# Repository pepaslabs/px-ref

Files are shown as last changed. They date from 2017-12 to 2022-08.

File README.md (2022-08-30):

# PX Ref

This is an LTZ1000-based 7V reference.

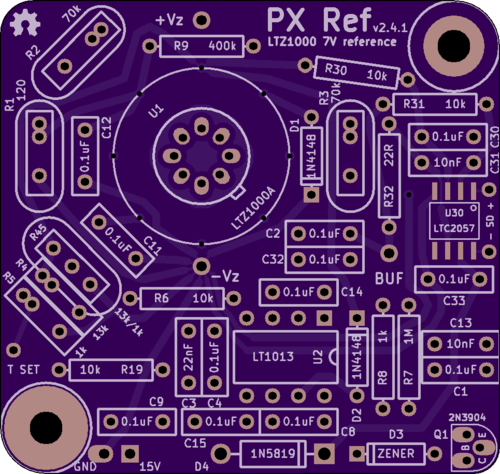
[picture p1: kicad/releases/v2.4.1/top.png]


Specifically, this is my board layout of a circuit [published](http://www.eevblog.com/forum/metrology/ultra-precision-reference-ltz1000/msg249123/#msg249123) by Andreas (of the EEVBlog forum), which in turn is a modification of the 7V reference circuit from the [datasheet](http://cds.linear.com/docs/en/datasheet/1000afe.pdf).

## Latest revision

- [v2.4.3](kicad/releases/v2.4.3)

## Revision history:

- [v2.4.3](kicad/releases/v2.4.3)
  - Shortened the board very slightly, as the fit in a [TEKO 371.16](http://www.tekoenclosures.com/en/products/family/RF/series/37-39) was just a bit tight.
  - Added two 0.1" holes near LTZ1000 to allow securing a 3D-printed cap.
  - Added more via's in the thermal equalization ring around the LTZ1000.
- [v2.4.2](kicad/releases/v2.4.2)
  - ???
- [v2.4.1](kicad/releases/v2.4.1)
  - Used larger pads on the TO-99 footprint (easier to solder).
  - Moved the input and (buffered) output caps directly onto the board. 
- [v2.4](kicad/releases/v2.4)
  - The board is slightly smaller and fits within a [TEKO 371.16](http://www.tekoenclosures.com/en/products/family/RF/series/37-39) enclosure.
  - The chassis-ground jumper has been removed (these can now be linked with a small wire).
  - The center pin of the R4/R5 divider has been exposed ("T SET") for off-board manipulation.
  - The LTC2057 shutdown pins have been exposed for off-board control.
- [v2.3](kicad/releases/v2.3)
  - The "b" variant has been merged back into a single board design (R4, R5 and R45 are now all on the same board design).
  - The LTC2057 shutdown pins are now left floating.
- [v2.2](kicad/releases/v2.2), [v2.2b](kicad/releases/v2.2b)
  - 2.2 uses a single divider footprint (called R45) for R4 and R5.
  - 2.2b uses separate footprints for R4 and R5.
  - An output buffer was added (LTC2057).
  - **Errata:**
    - A mistake was made with the LTC2057 shutdown pins which will result in self-heating of a few degrees in the LTC2057.  The work-around is to disconnect pins 1 and 8 of the LTC2057. 
- [v2.1](kicad/releases/v2.1)
  - Added a jumper to optionally link GND to a chassis standoff.
  - Used smaller capacitor footprints.
  - Exposed the star ground as a solderable terminal.
  - Switched D1 from a 1N4001 to a 1N4148.
  - Used smaller footprints for D1 and D2.
  - **Errata:**
    - Andreas capacitor C15 was accidentally left off of this board design.  This cap isn't critical, but a work-around is to bodge a 0.1uF cap across pins 5-6 of the LT1013.
- [v2](kicad/releases/v2)
  - Switched to a simpler, 2-layer, 50mm x 50mm board design.
- [v1](kicad/releases/v1)
  - First design.  4-layer with via stitching for a mild EMI shielding effect.
  - This board was never ordered and tested.

## Schematic

Andreas' original schematic: [png](media/LTZ1KA_1b.PNG)

My adapted version of Andreas' schematic: [pdf](kicad/releases/v2.4.1/basic-ltz1000.pdf)

## Purchasing

You can order a copy of this board from OSHPark: [link](https://oshpark.com/shared_projects/hUZKe65r)

## Discussion

My posts to the EEVBlog forum about this design: [link](http://www.eevblog.com/forum/metrology/ultra-precision-reference-ltz1000/msg1375209/#msg1375209) [link](http://www.eevblog.com/forum/metrology/px-reference/)

The naming of this board was inspired by other LTZ1000 references: [KX](https://xdevs.com/article/kx-ref/), [FX](https://xdevs.com/article/792x/), [MX](https://www.eevblog.com/forum/metrology/mx-reference/), [CX](https://www.eevblog.com/forum/metrology/cx-reference/), [QX](http://www.eevblog.com/forum/metrology/ultra-precision-reference-ltz1000/msg1377719/#msg1377719)

See also:
- https://github.com/pepaslabs/dr-frank-ltz1000
- https://github.com/pepaslabs/hp-03458-66509-clone

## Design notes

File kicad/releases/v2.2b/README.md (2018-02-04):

This board is identical to the 2.2 board, with the exception of the R4 / R5 divider being broken out into two discrete resistor footprints.

## Errata

A mistake was made with the LTC2057 shutdown pin which will cause self-heating of 2057 by a few degrees.

The shutdown pin's maximum input rating is 5.3V, but it was connected to the 15V supply, which will result in 1mA flowing through its internal 10k resistor and 5.25V protection zener, burning an additional 15mW of heat inside of the 2057.  This could raise the internal temperature of the 2057 by a few degrees and possible lead to a few uV of thermal EMF error on one of the pins.

The solution is to detach pins 1 and 8 of the 2057 (the shutdown pin will function normally if those pins are left floating).

## Bill of materials (BOM):

See the [2.2 README](../v2.2/README.md).

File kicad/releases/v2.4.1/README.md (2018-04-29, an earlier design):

# PX Ref v2.4.1



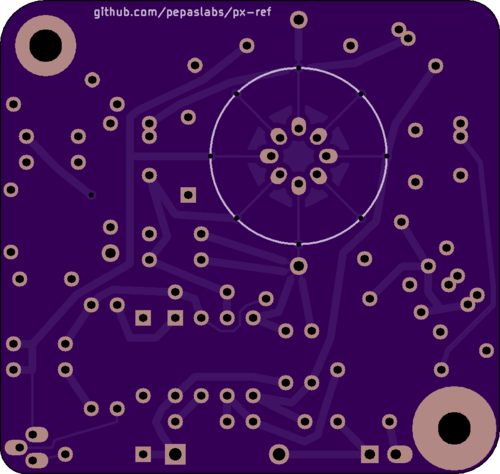
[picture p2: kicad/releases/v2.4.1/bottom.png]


## Bill of materials (BOM)



Spreadsheet: [link](https://docs.google.com/spreadsheets/d/1Y3n63W4g9fGwFwLfaXiGHgZg_IhSQoVIadUeNRAaL08/edit?usp=sharing)

## Parts from the datasheet schematic:

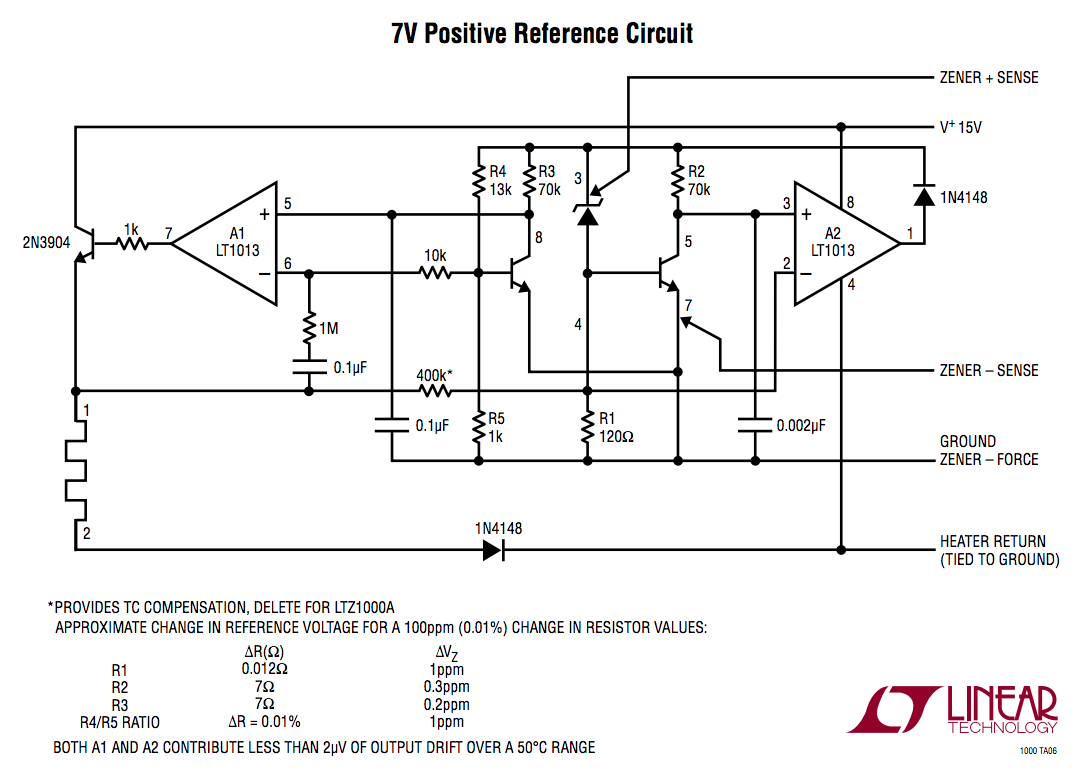
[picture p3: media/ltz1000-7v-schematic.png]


### U1

LTZ1000 or LTZ1000A.

### U2

LT1013 in DIP8.

### Q1

2N3904 in TO-92.

### R1, R2, R3, R4 / R5, R45

These are the "critical" resistors.

These footprints are intended for Vishay or AE metal foil resistors, in either the hermetic "metal can" package, or the "box" epoxy package.

R45 is for a Vishay "voltage divider" resistor set.  R4 and R5 are discrete footprints for the same divider.  Populate either R45 or R4 and R5.

R1 sets the current through the zener.

The ratio of R4 to R5 sets the temperature set-point of the heater circuit.
The 13:1 ratio is just the value given in the datasheet -- you can tweak this lower or higher to suit your needs.  I've used between 12.2:1 and 12.5:1 successfully.
If the ratio is too low, the LTZ will fall out of thermal regulation (you'll know that this happens because the temperature coefficient will be 50ppm/C).
Increasing the ratio allows for operation in a higher-temperature ambient environment (HP uses a 15:1 ratio in their 3458A), but will increase the ageing rate of the LTZ1000.

Note that the common terminal between R4 and R5 has been brough out via the "TSET" pin.  This can be used to alter the temperature set-point, e.g. for implementing an (off-board) "[Pickering patent](https://patents.google.com/patent/US5369245)" hystersis treatment.

#### Relative impact of R1 - R5

Several members of the EEVBlog forums have emperically measured the impact of drift in these resistors.  I have summarized their results here: [link](https://www.eevblog.com/forum/metrology/resistor-set-for-ltz1000-positive-standard-7v-circuit/msg1386014/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)

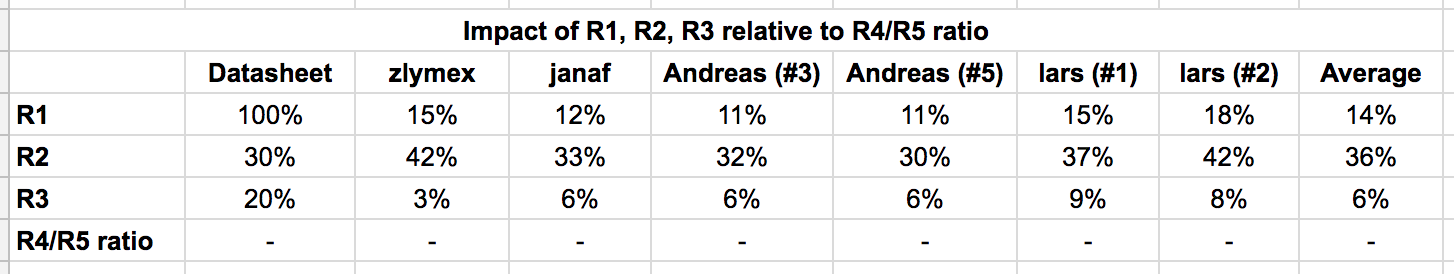
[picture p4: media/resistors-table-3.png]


Some obvervations, just to check your understanding:

The drift of R3 is only 6% as important as the drift of the R4/R5 ratio.  That is, if R4/R5 drifted by 1ppm, R3 would have to drift by over 16ppm to have the same impact on the reference ouput.

The temperature coefficient of one of the 70k resistors (R2) is six times more important than the other 70k resistor (R3).

The R4/R5 ratio is about 3x more important than R2, about 7x more important than R1, and about 16x more important than R3.

### R6, R7, R8, R9

Nothing fancy here, just 1% metal film 1/4 Watt resistors.  The reference board in HP's 3458A has them spec'ed as being 100ppm/C.

- R6: 10k
- R7: 1M
- R8: 1k

R9 is optional and is used to tune the temperature coefficient of the circuit.  The datasheet recommends using it with the LTZ1000 and omitting it with the LTZ1000A.  Try experimenting with this value in either case.

- R9: 400k

### C1, C2, C3

I chose to use film capacitors here to avoid the microphonic sensitivity of ceramic capacitors.

- C1, C2: 0.1uF

The datasheet specifies 2nF for C3, but most circuits I've seen use 22nF.  A forum member claims using 2nF causes the control loop to be a bit "ringy".  In fact, the negative version of the circuit in the datasheet specifies 22nF, so I'm curious if 2nF for the 7V schematic was a typo.

- C3: 22nF

### D1, D2

1N4148.

## Parts from Andreas' schematic:

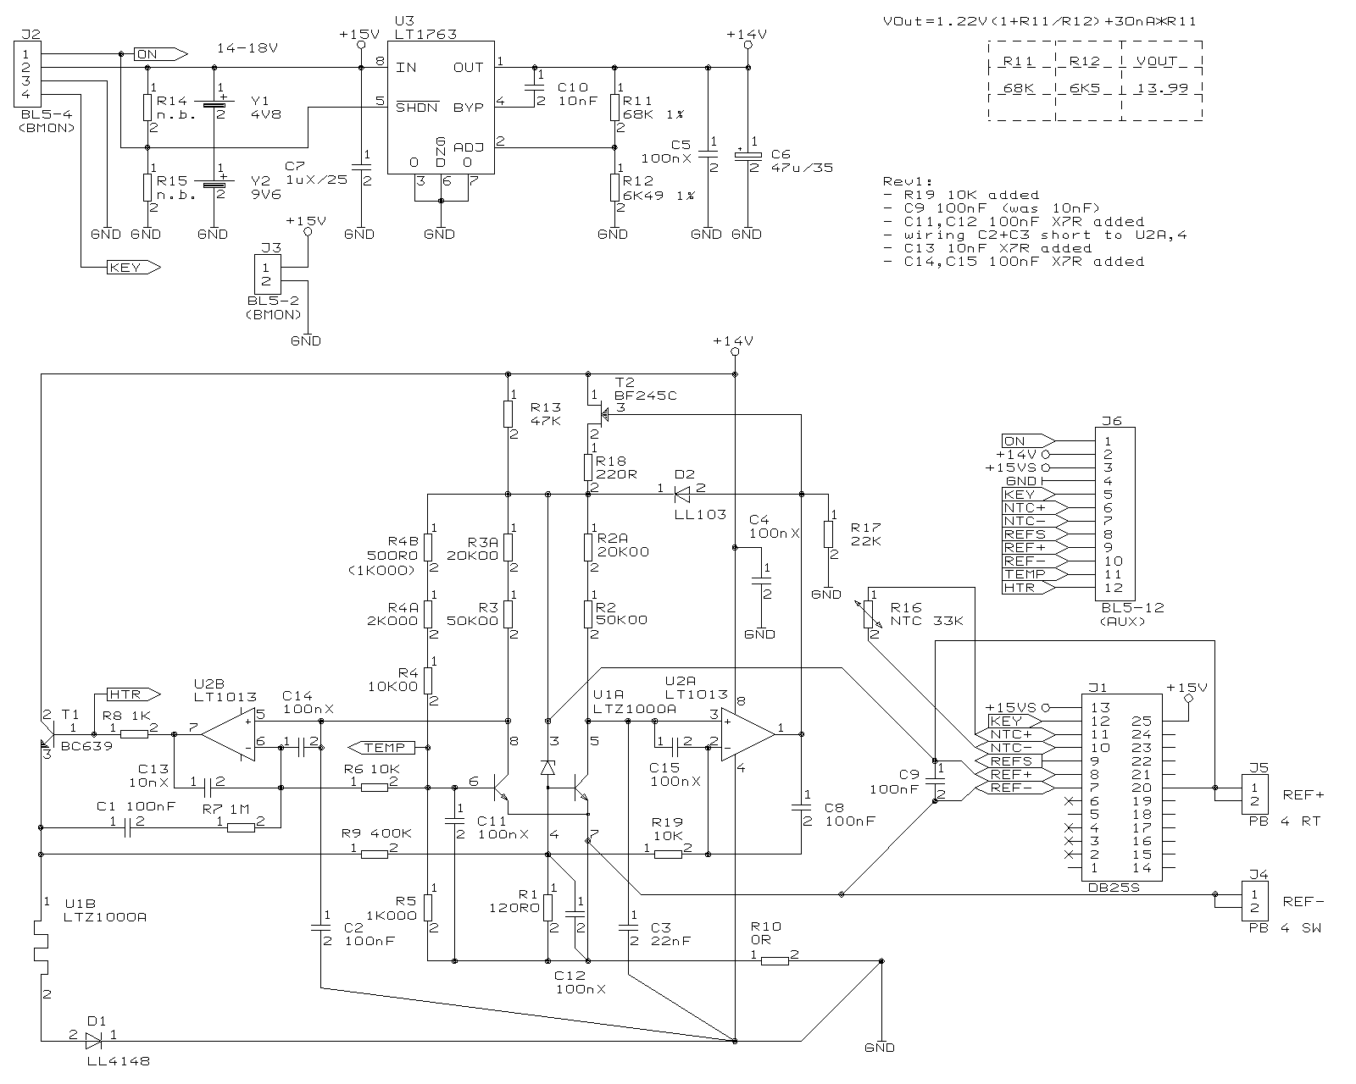
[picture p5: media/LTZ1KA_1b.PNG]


### C8, C11, C12, C13, C14, C15

Andreas has added these capacitors for stability and EMI suppression.

- C13: 10nF
- C8, C11, C12, C14, C15: 0.1uF

### C9

0.1uF, the input capacitor.

## Parts I've added:



Schematic: [pdf](basic-ltz1000.pdf)

### C4

0.1uF, for the LT1013 supply.

### D4

This diode is for reverse polarity protection on the 15V supply.

I chose to go with a 1 amp Shottky diode (1N5817, 1N1518, or 1N1519)
because it has a lower voltage drop than a regular 1 amp diode (1N4001, etc),
but nearly any diode will work here.
A lower voltage drop would be desireable when running the board from a 12V lead acid battery.

Results of testing voltage drop at 20mA of a few diodes I had on hand:
- 1N5817: 0.23V
- 1N5819: 0.29V
- 1N4001: 0.71V
- 1N4006: 0.73V
- 1N4148: 0.78V

## D3

This part is optional -- you can just solder in a jumper wire instead.

This is a zener diode which was suggested by a forum member,
which limits the initial in-rush current of a cold LTZ1000 heater.
Perhaps this could be useful in reducing power-cycle induced hysteresis?

Please note that this is just speculation -- I don't yet have any data which demonstrates this part to be beneficial.

Monitoring the emitter of the 2N3904 on startup with the board driven from a 15V supply (populated with an LTZ1000A) showed that the emitter voltage was at about 6.3V at ~1 second, slowly falling to about 5.26V after a few minutes.
This was with an uncovered LTZ1000A at 73F ambient.

So, what's a good value for D3?
If we consider the minimum supply voltage for this board to be 11.6V
(a nearly discharged 12V lead acid battery),
and we allow 7V for the heater at start-up,
0.7V drop across the 2N3904,
and 0.3V drop across the 1N5819,
that leaves us with (11.6 - 7 - 0.7 - 0.3) = 3.6V.

So, a 3.3V zener would be a conservative choice here.

Alternatively, a shunt resistor could be soldered in D3's place if you needed to monitor the heater current.

### Mounting holes

These holes are intended to accomodate M3 brass hex standoffs.

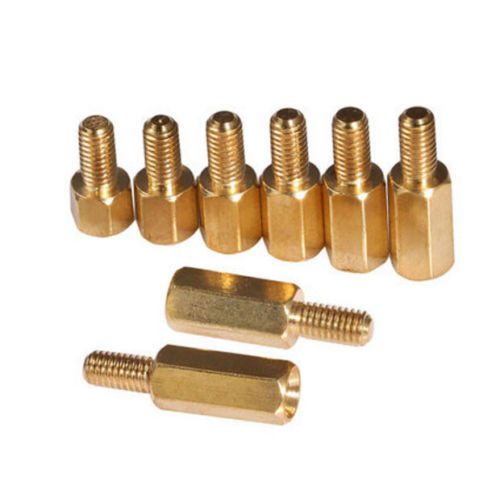
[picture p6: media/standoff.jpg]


Ideally, only one mounting hole should be secured with a nut.
The other should "float", allowing the board to expand and contract freely with temperature
(bending the baord can put stress on the components, causing tiny shifts in output voltage).

Note that the copper pad of one of the mounting holes has been enlarged.  This is to facilitate soldering a connection between chassis and ground (the ground pin is adjacent to this mounting hole).

## Ouput buffer:

### U30

LTC2057 in SOIC-8.

Note that the "shutdown" functionality has been brought out via the "-SD+" pins.  This might be useful if implementing an (off-board) output shutdown mechanism.  For example, I plan on implementing a mechanism where the output isn't enabled until the temperature of the board's oven has stabilized.

### R30, R31, R32

1% metal film.

- R30, R31: 10k
- R32: 22R

### C30, C31, C32, C33

More film caps.

- C31: 10nF
- C30, C32, C33: 0.1uF

C32 is the (buffered) output capacitor.

## Changes from previous board revision

- Used larger pads for the TO-99 footprint (they were too difficult to solder).
- Moved the input and output capacitors directly onto the board (instead of mounted across the banana jacks).

## Choosing Vsupply

Andreas of the EEVBlog forums has shown that the PSRR of this cicruit is essentially linear at least down to 9V.

https://www.eevblog.com/forum/metrology/ultra-precision-reference-ltz1000/msg842662/#msg842662

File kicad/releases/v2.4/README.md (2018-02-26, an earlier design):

# PX Ref v2.4

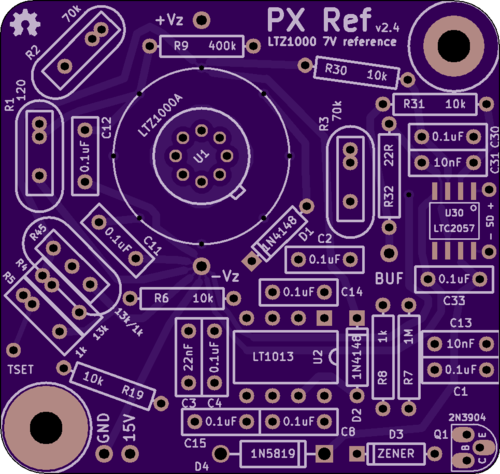
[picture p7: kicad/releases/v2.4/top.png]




## Bill of materials (BOM)

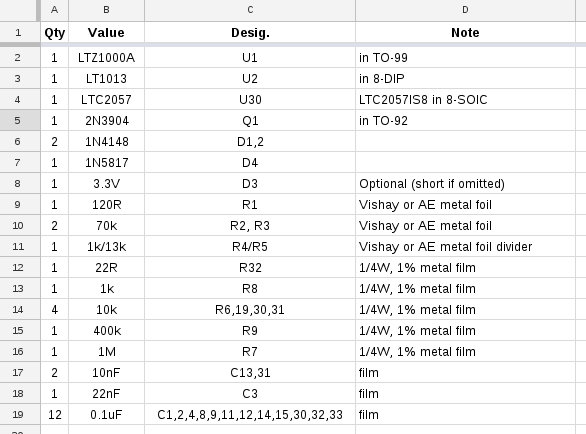
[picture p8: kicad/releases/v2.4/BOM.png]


Spreadsheet: [link](https://docs.google.com/spreadsheets/d/1Y3n63W4g9fGwFwLfaXiGHgZg_IhSQoVIadUeNRAaL08/edit?usp=sharing)

## Parts from the datasheet schematic:



### U1

LTZ1000 or LTZ1000A.

### U2

LT1013 in DIP8.

### Q1

2N3904 in TO-92.

### R1, R2, R3, R4 / R5, R45

These are the "critical" resistors.

These footprints are intended for Vishay or AE metal foil resistors, in either the hermetic "metal can" package, or the "box" epoxy package.

R45 is for a Vishay "voltage divider" resistor set.  R4 and R5 are discrete footprints for the same divider.  Populate either R45 or R4 and R5.

R1 sets the current through the zener.

The ratio of R4 to R5 sets the temperature set-point of the heater circuit.
The 13:1 ratio is just the value given in the datasheet -- you can tweak this lower or higher to suit your needs.  I've used between 12.2:1 and 12.5:1 successfully.
If the ratio is too low, the LTZ will fall out of thermal regulation (you'll know that this happens because the temperature coefficient will be 50ppm/C).
Increasing the ratio allows for operation in a higher-temperature ambient environment (HP uses a 15:1 ratio in their 3458A), but will increase the ageing rate of the LTZ1000.

Note that the common terminal between R4 and R5 has been brough out via the "TSET" pin.  This can be used to alter the temperature set-point, e.g. for implementing an (off-board) "[Pickering patent](https://patents.google.com/patent/US5369245)" hystersis treatment.

#### Relative impact of R1 - R5

Several members of the EEVBlog forums have emperically measured the impact of drift in these resistors.  I have summarized their results here: [link](https://www.eevblog.com/forum/metrology/resistor-set-for-ltz1000-positive-standard-7v-circuit/msg1386014/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)



Some obvervations, just to check your understanding:

The drift of R3 is only 6% as important as the drift of the R4/R5 ratio.  That is, if R4/R5 drifted by 1ppm, R3 would have to drift by over 16ppm to have the same impact on the reference ouput.

The temperature coefficient of one of the 70k resistors (R2) is six times more important than the other 70k resistor (R3).

The R4/R5 ratio is about 3x more important than R2, about 7x more important than R1, and about 16x more important than R3.

### R6, R7, R8, R9

Nothing fancy here, just 1% metal film 1/4 Watt resistors.  The reference board in HP's 3458A has them spec'ed as being 100ppm/C.

- R6: 10k
- R7: 1M
- R8: 1k

R9 is optional and is used to tune the temperature coefficient of the circuit.  The datasheet recommends using it with the LTZ1000 and omitting it with the LTZ1000A.  Try experimenting with this value in either case.

- R9: 400k

### C1, C2, C3

I chose to use film capacitors here to avoid the microphonic sensitivity of ceramic capacitors.

- C1, C2: 0.1uF

The datasheet specifies 2nF for C3, but most circuits I've seen use 22nF.  A forum member claims using 2nF causes the control loop to be a bit "ringy".  In fact, the negative version of the circuit in the datasheet specifies 22nF, so I'm curious if 2nF for the 7V schematic was a typo.

- C3: 22nF

### D1, D2

1N4148.

## Parts from Andreas' schematic:



### C8, C11, C12, C13, C14, C15

Andreas has added these capacitors for stability and EMI suppression.

- C13: 10nF
- C8, C11, C12, C14, C15: 0.1uF

### C9

0.1uF, the output capacitor.  Solder this to the output binding posts.

## Parts I've added:



Schematic: [pdf](basic-ltz1000.pdf)

### C4

0.1uF, for the LT1013 supply.

### D4

This diode is for reverse polarity protection on the 15V supply.

I chose to go with a 1 amp Shottky diode (1N5817, 1N1518, or 1N1519)
because it has a lower voltage drop than a regular 1 amp diode (1N4001, etc),
but nearly any diode will work here.
A lower voltage drop would be desireable when running the board from a 12V lead acid battery.

Results of testing voltage drop at 20mA of a few diodes I had on hand:
- 1N5817: 0.23V
- 1N5819: 0.29V
- 1N4001: 0.71V
- 1N4006: 0.73V
- 1N4148: 0.78V

## D3

This part is optional -- you can just solder in a jumper wire instead.

This is a zener diode which was suggested by a forum member,
which limits the initial in-rush current of a cold LTZ1000 heater.
Perhaps this could be useful in reducing power-cycle induced hysteresis?

Please note that this is just speculation -- I don't yet have any data which demonstrates this part to be beneficial.

Monitoring the emitter of the 2N3904 on startup with the board driven from a 15V supply (populated with an LTZ1000A) showed that the emitter voltage was at about 6.3V at ~1 second, slowly falling to about 5.26V after a few minutes.
This was with an uncovered LTZ1000A at 73F ambient.

So, what's a good value for D3?
If we consider the minimum supply voltage for this board to be 11.6V
(a nearly discharged 12V lead acid battery),
and we allow 7V for the heater at start-up,
0.7V drop across the 2N3904,
and 0.3V drop across the 1N5819,
that leaves us with (11.6 - 7 - 0.7 - 0.3) = 3.6V.

So, a 3.3V zener would be a conservative choice here.

Alternatively, a shunt resistor could be soldered in D3's place if you needed to monitor the heater current.

### Mounting holes

These holes are intended to accomodate M3 brass hex standoffs.



Ideally, only one mounting hole should be secured with a nut.
The other should "float", allowing the board to expand and contract freely with temperature
(bending the baord can put stress on the components, causing tiny shifts in output voltage).

Note that the copper pad of one of the mounting holes has been enlarged.  This is to facilitate soldering a connection between chassis and ground (the ground pin is adjacent to this mounting hole).

## Ouput buffer:

### U30

LTC2057 in SOIC-8.

Note that the "shutdown" functionality has been brought out via the "-SD+" pins.  This might be useful if implementing an (off-board) output shutdown mechanism.  For example, I plan on implementing a mechanism where the output isn't enabled until the temperature of the board's oven has stabilized.

### R30, R31, R32

1% metal film.

- R30, R31: 10k
- R32: 22R

### C30, C31, C32, C33

More film caps.

- C31: 10nF
- C30, C32, C33: 0.1uF

C32 is the (buffered) output capacitor.  Solder it to the binding posts.

## Changes from previous board revision

- Board dimensions should now be small enough to squeeze into a TEKO 371.16 case (a steel case which can fit inside of a Hammond 1590B).  Such an arrangement should shield from both EMI as well as magnetic fields.
- The "shutdown" pins of the LTC2057 have been exposed via break-out pins (for implementing off-board control).
- The center terminal of the R4 / R5 divider has been exposed via a breakout pin (for off-board manipulation of the temperature set-point).
- The chassis-ground jumper has been removed (You can solder a wire from ground to the pad of the adjacent mounting hole if you want ground to be connected to chassis via brass stand-offs).
- Minor routing tweaks.

## Choosing Vsupply

Andreas of the EEVBlog forums has shown that the PSRR of this cicruit is essentially linear at least down to 9V.

https://www.eevblog.com/forum/metrology/ultra-precision-reference-ltz1000/msg842662/#msg842662

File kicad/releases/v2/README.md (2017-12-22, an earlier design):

# PX Ref v2



## Errata:

I forgot to include the footprint for Andreas' C15, which is a 0.1uF capacitor across pins 5-6 of the LT1013.  This can be bodged in on the underside of the board.

## Parts from the datasheet schematic:



### U1

LTZ1000 or LTZ1000A.

### U2

LT1013 in DIP8.

### Q1

2N3904 in TO-92.

### R1, R2, R3, R4 / R5

These are the "critical" resistors.

R1 sets the current through the zener.
The ratio of R4 to R5 sets the temperature set-point of the heater circuit.

These footprints are intended for Vishay or AE metal foil resistors.  R4 / R5 is for a Vishay "voltage divider" resistor set.

### R6, R7, R8, R9

Nothing fancy here, just 1% metal film 1/4 Watt resistors.  The reference board in HP's 3458A has them spec'ed as being 100ppm/C.

- R6: 10k
- R7: 1M
- R8: 1k

R9 is optional and is used to tune the temperature coefficient of the circuit.  The datasheet recommends using it with the LTZ1000 and omitting it with the LTZ1000A.  Try experimenting with this value in either case.

- R9: 400k

### C1, C2, C3

I chose to use film capacitors here to avoid the microphonic sensitivity of ceramic capacitors.

- C1, C2: 0.1uF

The datasheet specifies 2nF for C3, but most circuits I've seen use 22nF.  A forum member claims using 2nF causes the control loop to be a bit "ringy".  In fact, the negative version of the circuit in the datasheet specifies 22nF, so I'm curious if 2nF for the 7V schematic was a typo.

- C3: 22nF

### D1, D2

The datasheet specifies 1N4148 here.  A forum member suggested using a 1N4001 for D1 to better handle the in-rush current of a cold unit, but the 1N4148 is spec'ed at 300mA continuous, so it should be fine.

## Parts from Andreas' schematic:



FIXME

## Parts I've added:



Schematic: [pdf](basic-ltz1000.pdf)

### D4

This diode is for reverse polarity protection on the 15V supply.

I chose to go with a 1 amp Shottky diode (1N5817, 1N1518, or 1N1519)
because it has a lower voltage drop than a regular 1 amp diode (1N4001, etc),
but nearly any diode will work here.
A lower voltage drop would be desireable when running the board from a 12V lead acid battery.

Results of testing voltage drop at 20mA of a few diodes I had on hand:
- 1N5817: 0.23V
- 1N5819: 0.29V
- 1N4001: 0.71V
- 1N4006: 0.73V
- 1N4148: 0.78V

## D3

This is a zener diode which was suggested by a forum member.  It's effect would be to limit the initial in-rush current to a cold LTZ1000 heater.

Monitoring the emitter of the 2N3904 on startup with the board driven from a 15V supply (populated with an LTZ1000A) showed that the emitter voltage was at about 6.3V at ~1 second, slowly falling to about 5.26V after a few minutes.  This was with an uncovered LTZ1000A at 73F ambient.

So, what's a good value for D3?  If we consider the minimum supply voltage for this board to be 11.6V (a nearly discharged 12V lead acid battery), and we allow 7V for the heater at start-up, and 0.7V drop across the 2N3904, that leaves us with (11.6 - 7 - 0.7) = 3.9V.

Testing with an LTZ1000A showed that the entire board stabilized to about 22mA of current consumption after a few seconds, with the voltage past D4 being about 14.78V.  Powering up the board cold using a current-limited power supply set to 

### Mounting holes

These holes are intended to accomodate M3 brass hex standoffs.



Ideally, only one mounting hole should be secured with a nut.
The other should "float", allowing the board to expand and contract freely with temperature
(bending the baord can put stress on the components, causing tiny shifts in output voltage).

## Bill of materials (BOM)

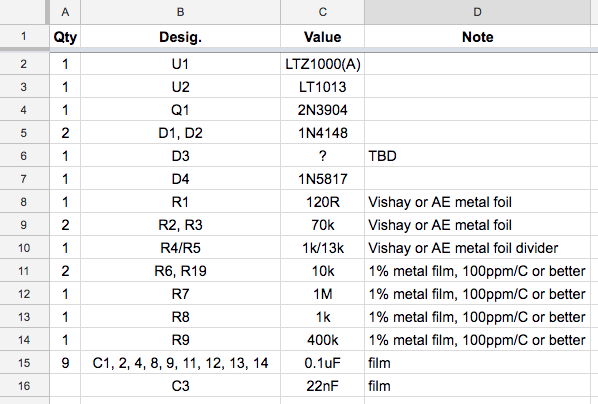
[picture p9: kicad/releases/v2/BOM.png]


Spreadsheet: [link](https://docs.google.com/spreadsheets/d/1iXBirF7wwRB60OcZYET5RVX0cuXblMtFNKk5hwqcZ_Y/edit?usp=sharing)

## TODO for next board revision

- Use slightly larger holes for the diodes (the 1N5817 is a bit of a tight fit).
- Swap the text labels of C13 to match the other caps
- Use 0.3" x 0.1" "skinny" footprints for the film caps.  The larger footprints are only needed for larger values of capacitance (e.g. 1uF).
- Make pin spacing of output pins compatible with 0.1" headers?
- Use the updated footprints (slightly larger silkscreen boundary) for R1-R3
- Add a current monitoring resistor footprint for the heater?
- Drop the 1N4001 to a 1N4148 as called for in the datasheet (it handles 300mA so there's no need for a 1N4001) and switch to the shorter lead spacing diode footprints for the two 1N4148's.

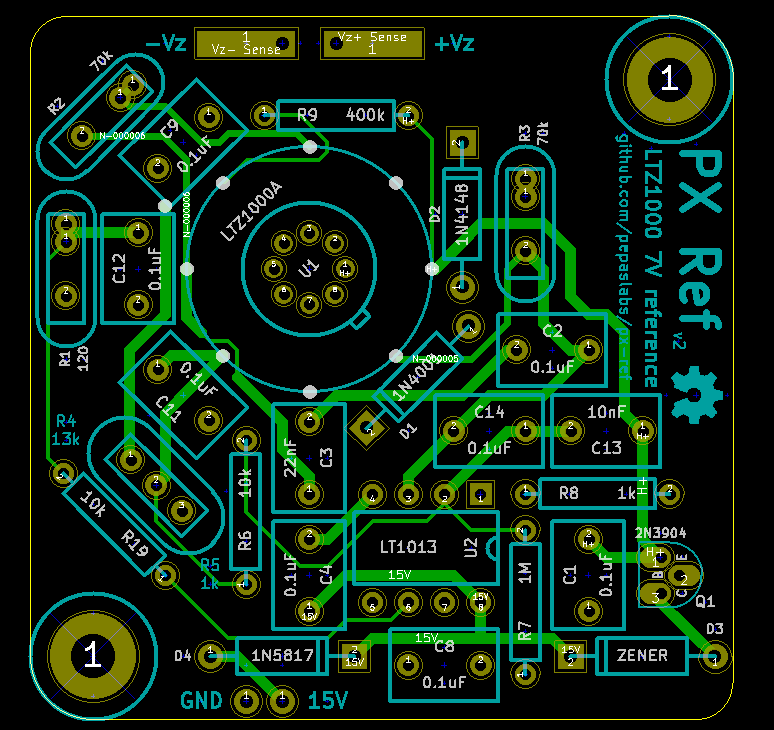
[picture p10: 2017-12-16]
media/kicad-bottom.png

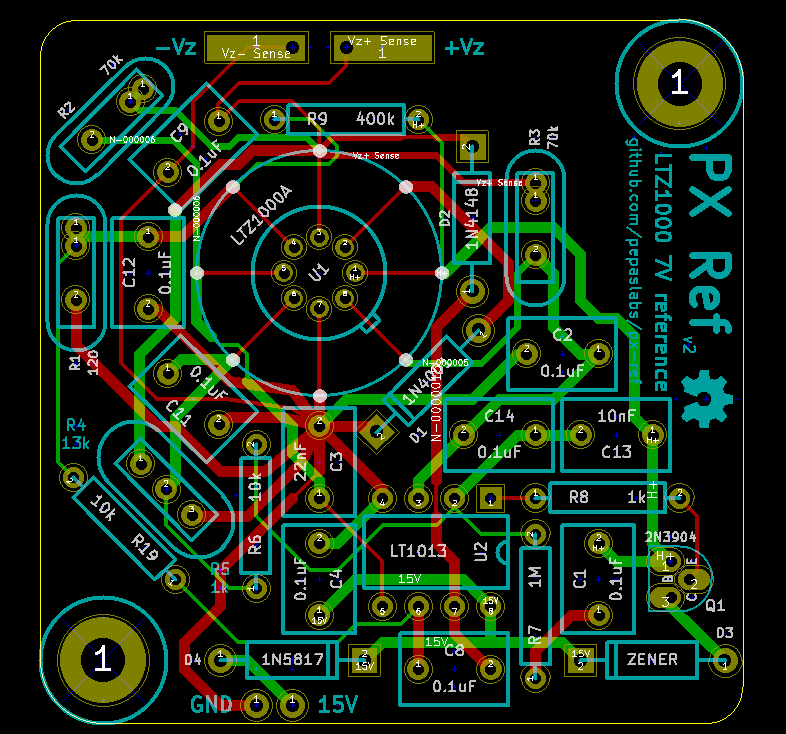
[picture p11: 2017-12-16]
media/kicad.png

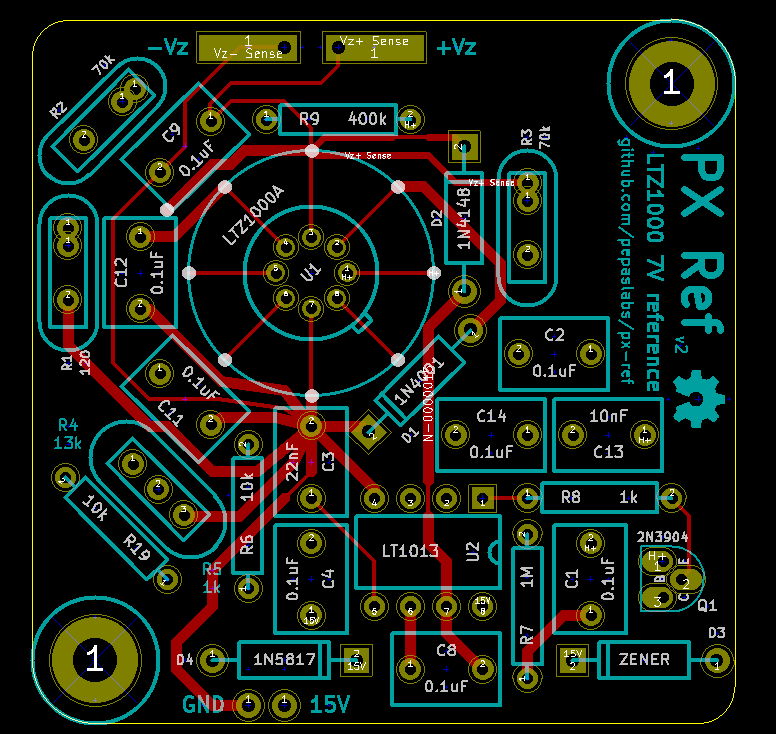
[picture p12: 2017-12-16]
media/kicad-top.png

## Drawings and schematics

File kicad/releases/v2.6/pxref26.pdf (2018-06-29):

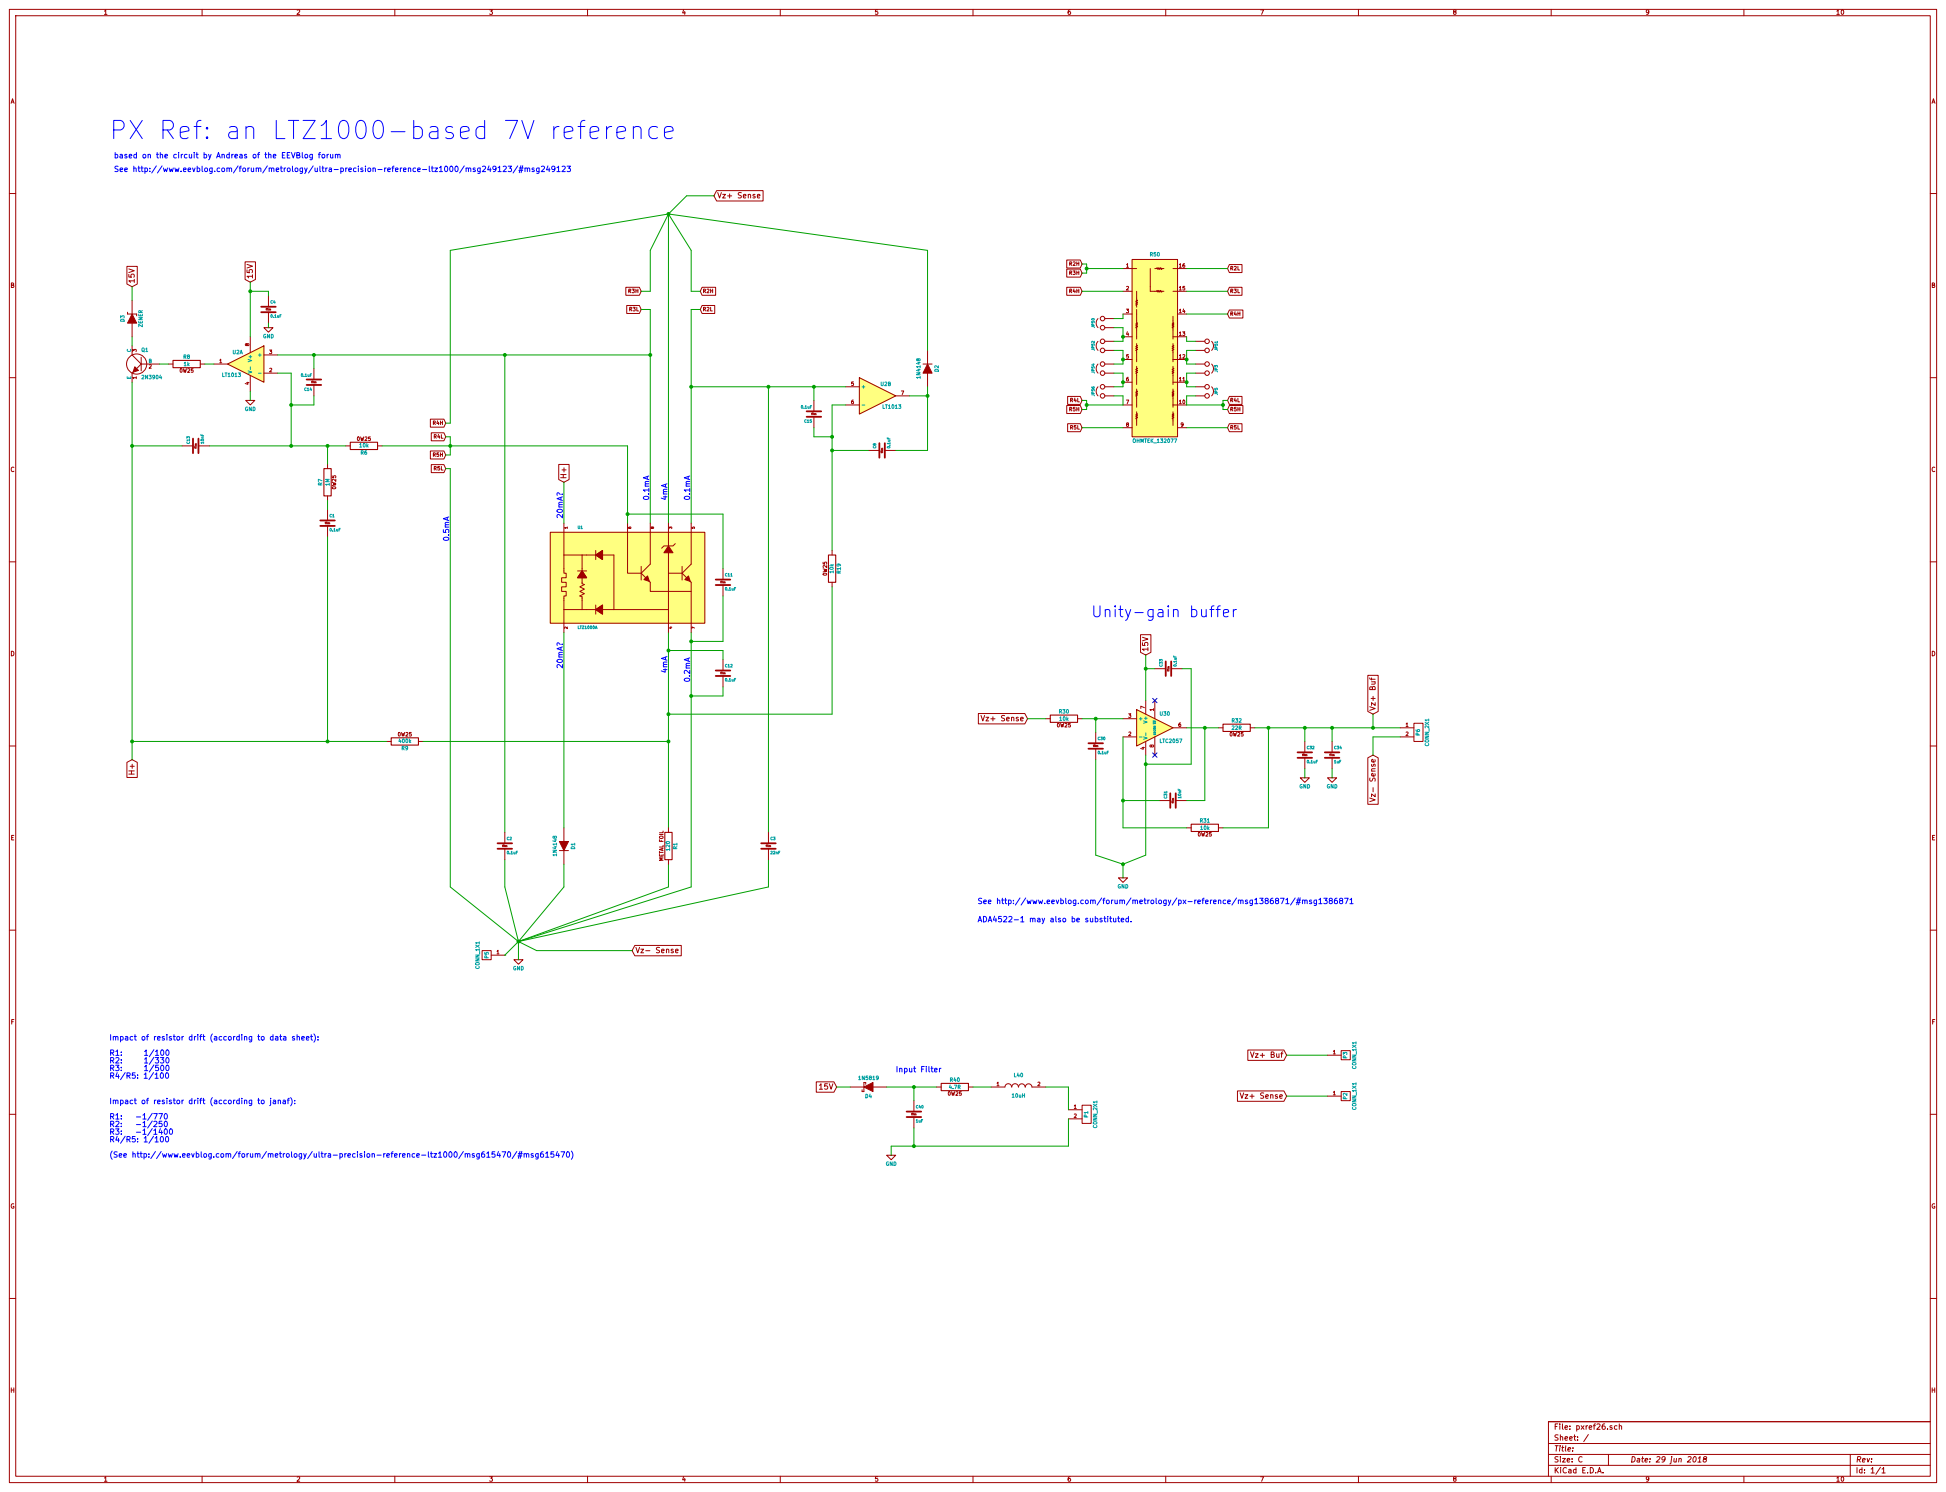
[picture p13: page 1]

PX Ref: an LTZ1000-based 7V reference

based on the circuit by Andreas of the EEVBlog forum
See http://www.eevblog.com/forum/metrology/ultra-precision-reference-ltz1000/msg249123/#msg249123

ADA4522-1 may also be substituted. 1

Impact of resistor drift (according to janaf):
(See http://www.eevblog.com/forum/metrology/ultra-precision-reference-ltz1000/msg615470/#msg615470)

Id: 1/1 Title: File: pxref26.sch
Sheet: /

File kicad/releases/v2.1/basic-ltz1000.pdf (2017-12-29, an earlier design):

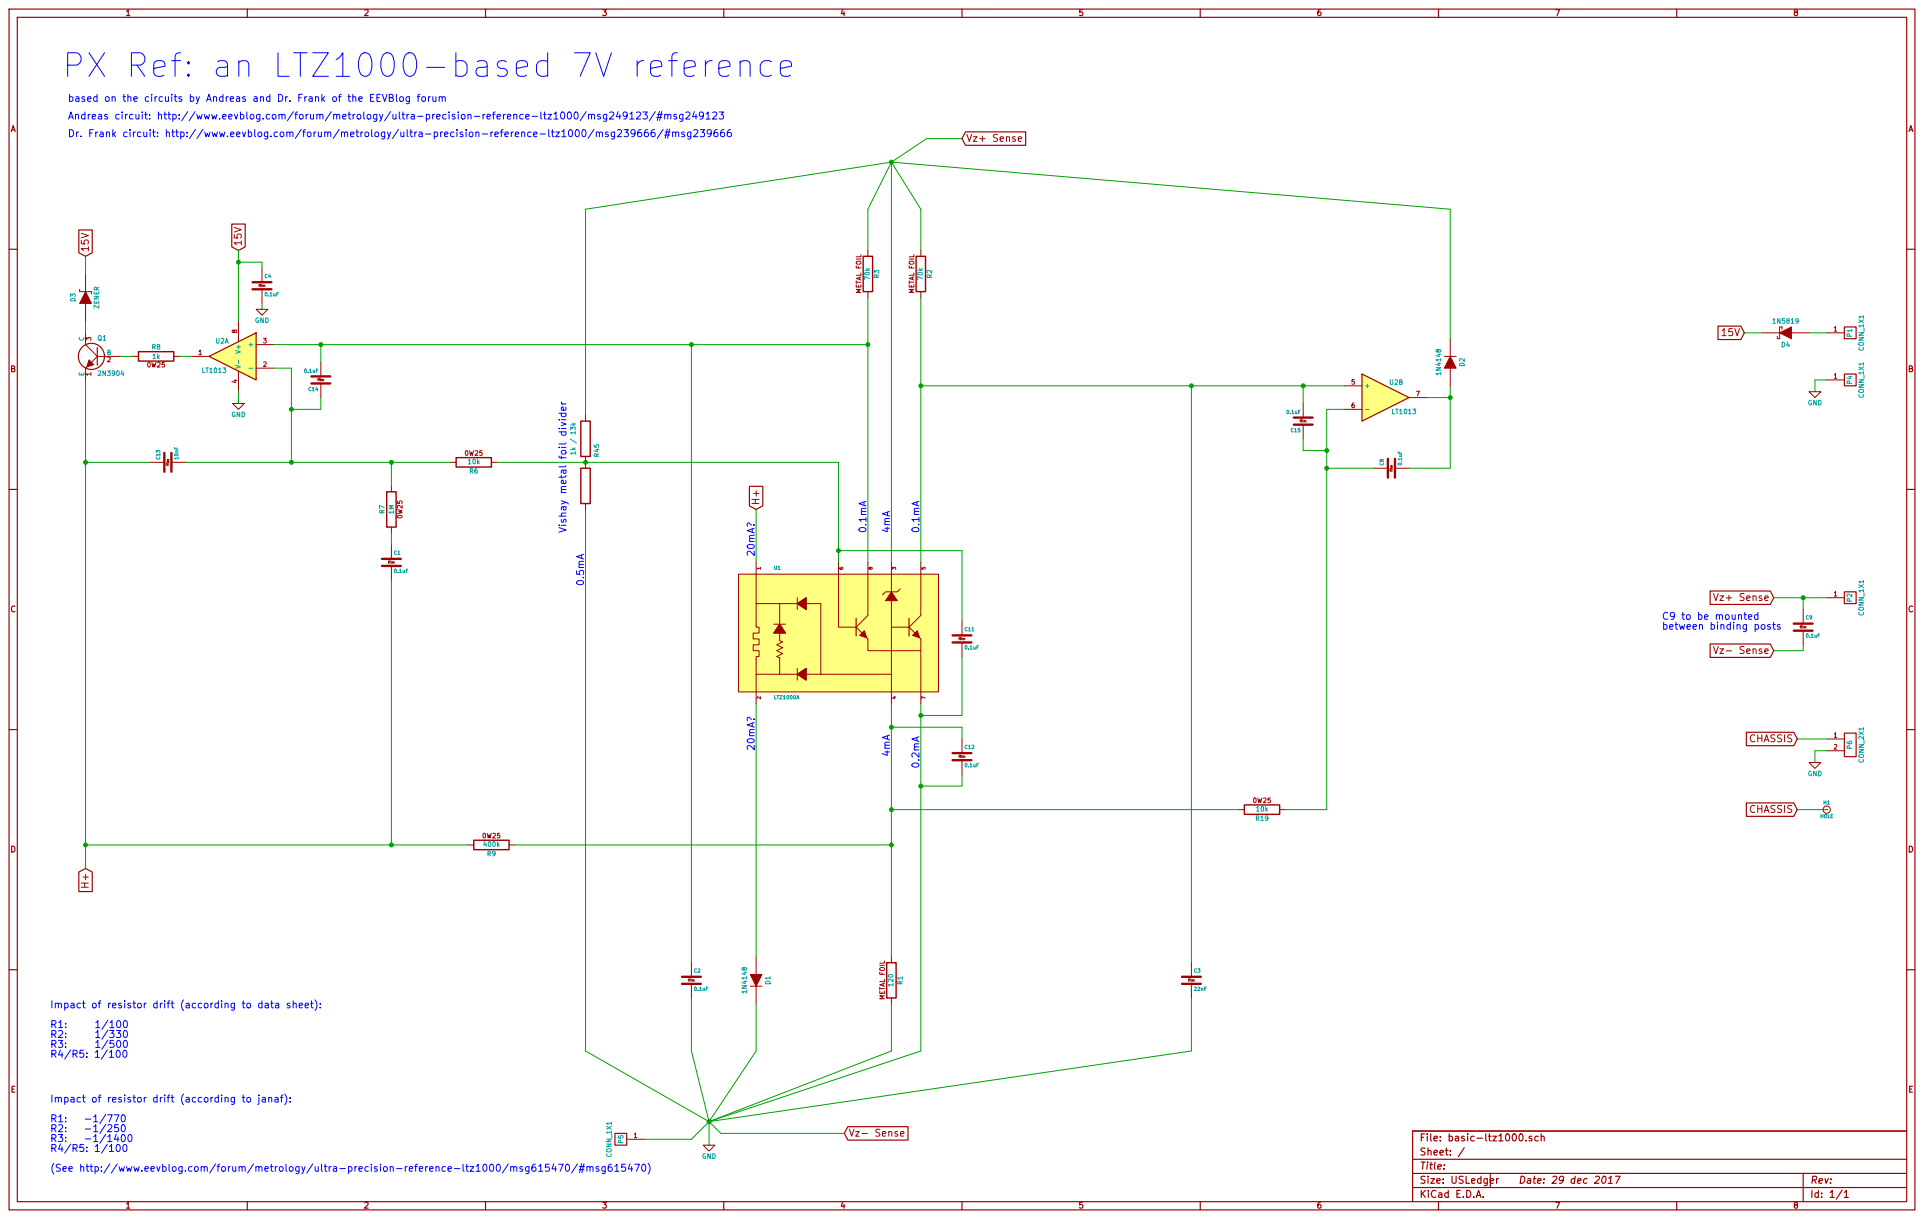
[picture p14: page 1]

PX Ref: an LTZ1000-based 7V reference

based on the circuits by Andreas and Dr. Frank of the EEVBlog forum
Andreas circuit: http://www.eevblog.com/forum/metrology/ultra-precision-reference-ltz1000/msg249123/#msg249123
Dr. Frank circuit: http://www.eevblog.com/forum/metrology/ultra-precision-reference-ltz1000/msg239666/#msg239666

H1 HOLE C9 to be mounted
between binding posts

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

Id: 1/1 Title: File: basic-ltz1000.sch Sheet: /

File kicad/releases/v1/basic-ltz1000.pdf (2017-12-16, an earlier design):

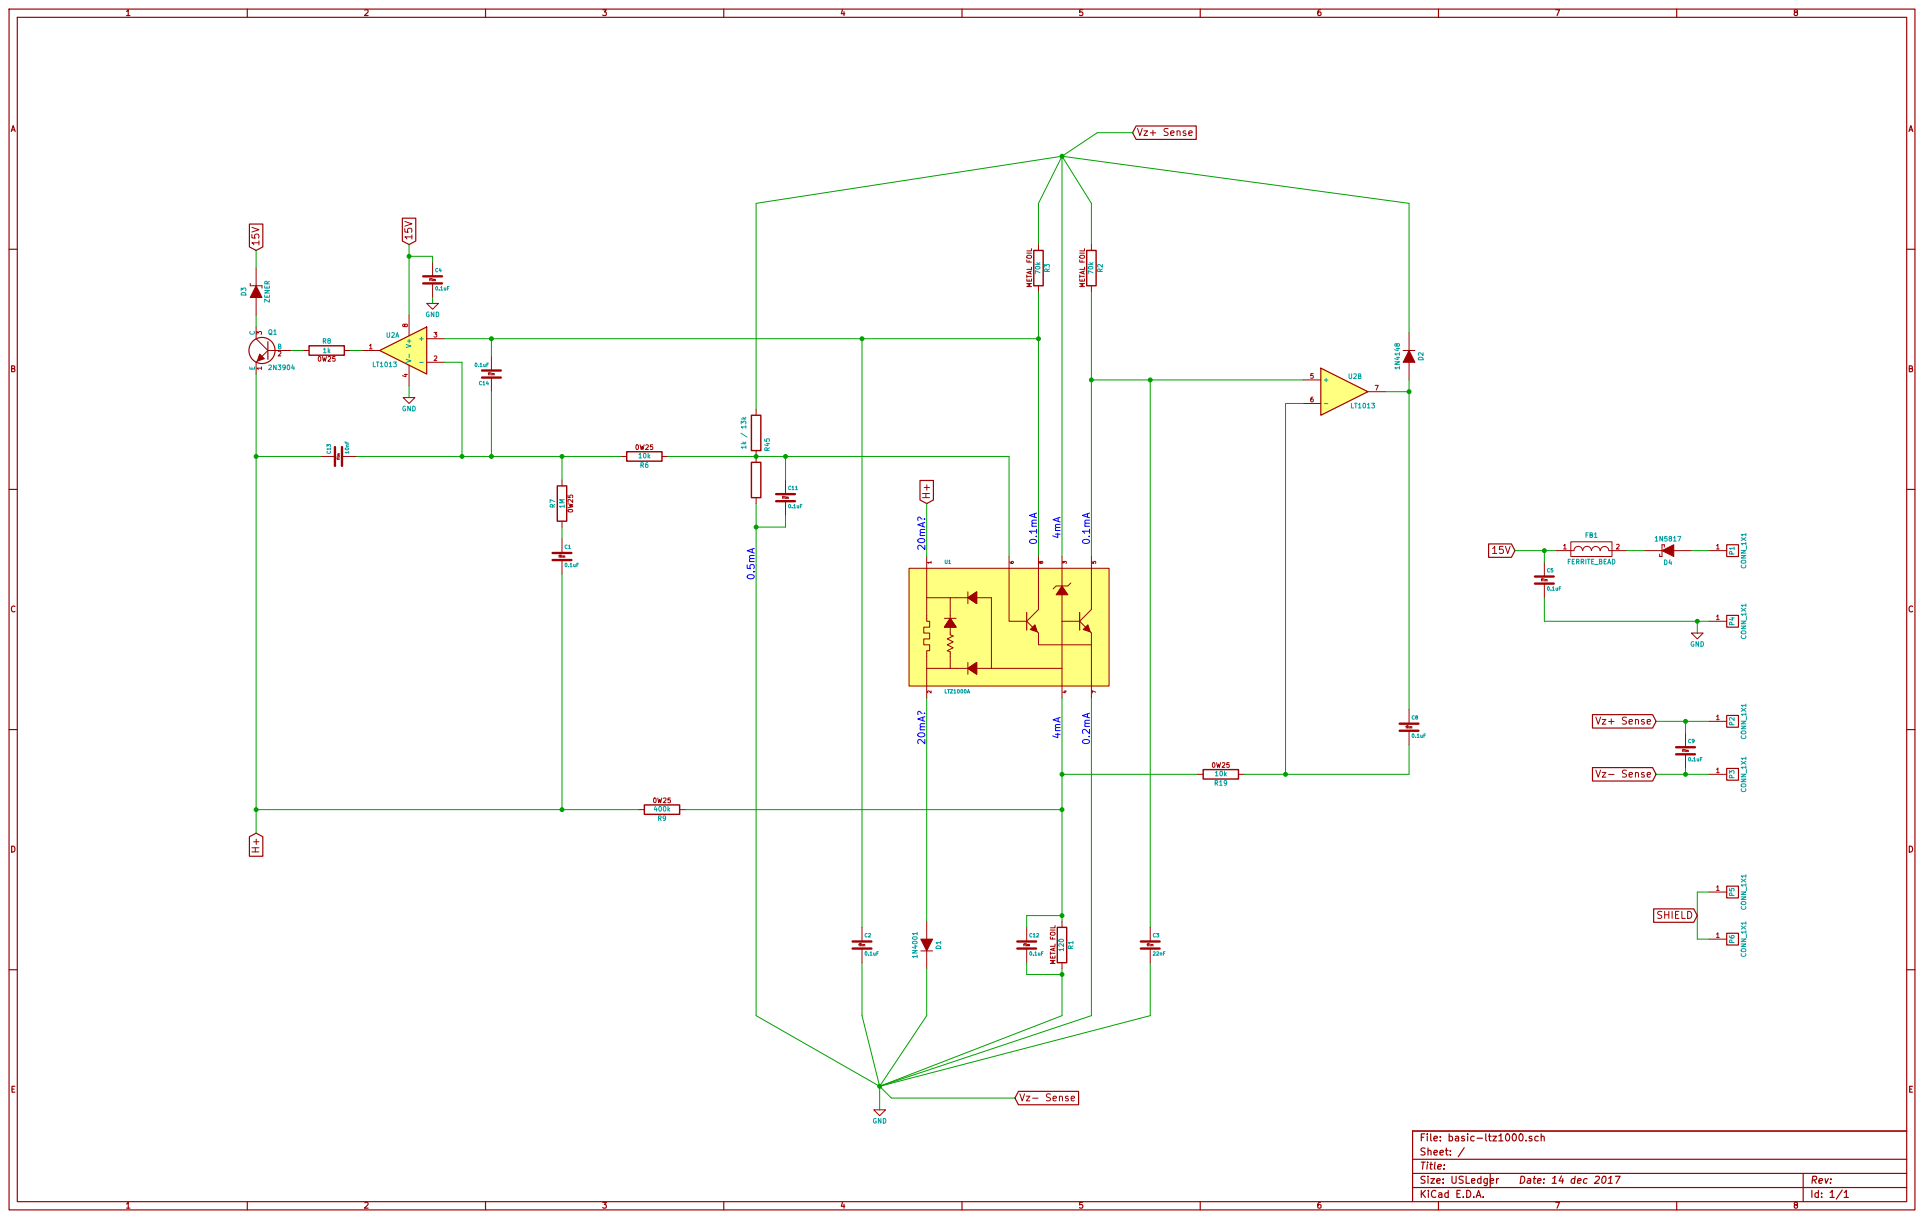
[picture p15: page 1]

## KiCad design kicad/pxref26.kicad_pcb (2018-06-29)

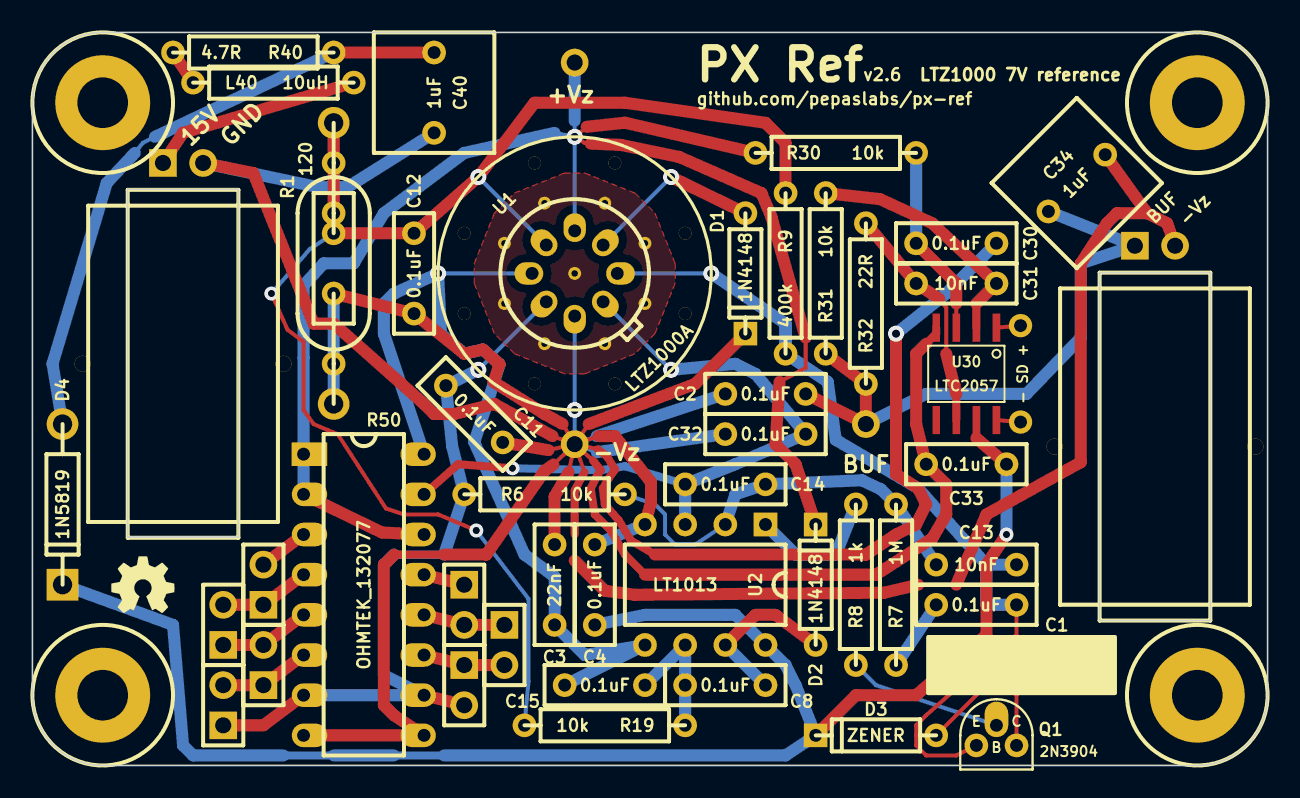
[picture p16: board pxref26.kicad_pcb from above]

Board: 2 copper layers, 78.1 x 46.4 mm, 71 parts (0 on the bottom side), 31 nets.

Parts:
C1, C2, C4, C8, C11, C12, C14, C15, C30, C32, C33: 0.1uF; BOXCAP_01_03_02_059A
C3: 22nF; BOXCAP_01_03_02_059A
C13, C31: 10nF; BOXCAP_01_03_02_059A
C34, C40: 1uF; BOXCAP_02_03_03_059A
D1, D2: 1N4148; DIODE_SS_059A_03_PL
D3: ZENER; DIODE_SS_059A_03_PL
D4: 1N5819; DIODE_1A_069A_04_PL
H1: HOLE; hole_M3
H***: Val**; hole_M3
H***#2, H***#3, H***#15, H***#16, H***#17, H***#18, H***#19, H***#20, H***#21, H***#22: Val**; 1pin_032_058
H***#4, H***#5, H***#6, H***#7, H***#8, H***#9, H***#10, H***#11, H***#12: Val**; Via_016
H***#13, H***#14: Val**; hole_M3
JP3, JP5, JP50, JP51, JP52, JP54, JP56: JUMPER2; SIL-2
L40: 10uH; R_AXIAL_0W25_059A_PL
P1, P6: CONN_2X1; ferrite_core_20x12_PL
P2, P3, P5: CONN_1X1; 1pin_040_069
Q1: 2N3904; TO-92_Q_EBC_059Bo_PL
R1: 120; R_BOX_HERMETIC_WW_AXIAL_07_PL
R6, R19, R30, R31: 10k; R_AXIAL_0W25_059A_PL
R7: 1M; R_AXIAL_0W25_059A_PL
R8: 1k; R_AXIAL_0W25_059A_PL
R9: 400k; R_AXIAL_0W25_059A_PL
R32: 22R; R_AXIAL_0W25_059A_PL
R40: 4.7R; R_AXIAL_0W25_059A_PL
R50: OHMTEK_132077; DIP16_PL
U1: LTZ1000A; TO-99_PL
U2: LT1013; DIP8_059A_PL
U30: LTC2057; SO-8

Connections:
15V: C4.1, C33.1, D3.2, D4.2, U2.8, U30.7
CHASSIS: H1.1, H***#4.~, H***#5.~, H***#6.~, H***#7.~, H***#8.~, H***#9.~, H***#10.~, H***#11.~, H***#12.~
H+: C1.2, C13.1, Q1.1, R9.2, U1.1
unnamed: L40.1, R40.2
unnamed: L40.2, P1.1
unnamed: C40.1, D4.1, R40.1
unnamed: JP54.1, JP56.2, R50.6
unnamed: C30.1, R30.2, U30.3
unnamed: C31.2, R32.1, U30.6
unnamed: C31.1, R31.1, U30.2
unnamed: JP3.1, JP51.2, R50.12
unnamed: JP51.1, R50.13
unnamed: JP52.1, JP54.2, R50.5
unnamed: JP50.1, JP52.2, R50.4
unnamed: JP50.2, R50.3
unnamed: JP3.2, JP5.1, R50.11
unnamed: C8.2, D2.1, U2.7
unnamed: C1.1, R7.1
unnamed: R8.1, U2.1
unnamed: D3.1, Q1.3
unnamed: Q1.2, R8.2
unnamed: D1.1, U1.2
unnamed: C12.1, R1.1, R9.1, R19.2, U1.4
unnamed: C13.2, C14.1, R6.2, R7.2, U2.2
unnamed: C8.1, C15.1, R19.1, U2.6
R2H: D2.2, P2.1, R30.1, R50.1, R50.2, R50.14, U1.3
R2L: C3.1, C15.2, R50.16, U1.5, U2.5
R3L: C2.1, C14.2, R50.15, U1.8, U2.3
R4L: C11.1, JP5.2, JP56.1, R6.1, R50.7, R50.10, U1.6
R5L: C2.2, C3.2, C4.2, C11.2, C12.2, C30.2, C32.2, C33.2, C34.2, C40.2, D1.2, P1.2, P5.1, P6.2, R1.2, R50.8, R50.9, U1.7, U2.4, U30.4
Vz+ Buf: C32.1, C34.1, P3.1, P6.1, R31.2, R32.2

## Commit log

2017-12-17 pulling in Andreas circuit
2017-12-21 adding png version of schematic
2017-12-21 adding BOM graphic
2017-12-27 Updating footprints for caps and diodes
    [basic-ltz1000.kicad_pcb, basic-ltz1000.sch]
2017-12-27 reroute WIP
    [basic-ltz1000.kicad_pcb, basic-ltz1000.sch]
2017-12-29 v2.1 gerbers
    [basic-ltz1000-B_Cu.gbl, basic-ltz1000-B_Mask.gbs, basic-ltz1000-B_SilkS.gbo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]
2017-12-29 adding v2.1 board renders
2017-12-29 adding v2.1 kicad shots
2017-12-29 v2.2 gerbers
    [basic-ltz1000-B_Cu.gbl, basic-ltz1000-B_Mask.gbs, basic-ltz1000-B_SilkS.gbo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]
2017-12-29 adding v2.2 board renders
2017-12-29 v2.2 revisions
    [basic-ltz1000-B_Cu.gbl, basic-ltz1000-B_Mask.gbs, basic-ltz1000-B_SilkS.gbo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]
2017-12-29 updated v2.2 board renders
2017-12-29 fixing output buffer, adding copper zones
    [basic-ltz1000-B_Cu.gbl, basic-ltz1000-B_Mask.gbs, basic-ltz1000-B_SilkS.gbo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]
2017-12-29 updating v2.2 board renders
2017-12-29 forgot the bottom copper board render
    [basic-ltz1000.sch]
2018-01-23 2.2b board shots
2018-02-04 adding BOM and README for v2.2
2018-02-04 adding board shots
2018-02-15 v2.4 gerbers
    [basic-ltz1000-B_Cu.gbl, basic-ltz1000-B_Mask.gbs, basic-ltz1000-B_SilkS.gbo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]
2018-02-16 silkscreen typo
    [basic-ltz1000-B_Cu.gbl, basic-ltz1000-B_Mask.gbs, basic-ltz1000-B_SilkS.gbo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]
2018-02-16 board shots
2018-06-24 adding vias
    [basic-ltz1000.kicad_pcb]
2018-06-24 branching files for 2.5.x
    [pxref25.kicad_pcb, pxref25.sch]
2018-06-25 splitting design into v2.4.x and v2.5.x
    [pxref24-B_Cu.gbl, pxref24-B_Mask.gbs, pxref24-B_SilkS.gbo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]
2018-06-27 2.6 schematic
    [pxref26.kicad_pcb, pxref26.sch]
2018-06-29 renaming board edge files to work with JLCPCB
    [pxref24-Edge_Cuts.gko, pxref25-Edge_Cuts.gko, pxref26-Edge_Cuts.gko]
2018-06-29 v2.4.2 board shots
2018-06-29 board shots v2.4.2
2018-06-29 board shots v2.6
2018-06-29 board shots v2.5
